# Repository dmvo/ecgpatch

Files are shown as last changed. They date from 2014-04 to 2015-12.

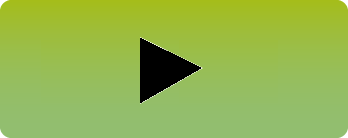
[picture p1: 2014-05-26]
ios/ECG/Pysty_Record.png

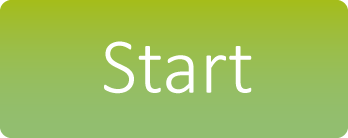
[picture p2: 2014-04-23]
ios/ECG/Pysty_Start.png

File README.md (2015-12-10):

ecgpatch
========

This repository contains source code related to the ECG patch
developed in Helsinki Metropolia University of Applied Sciences
in the context of the HealthSens project.

The code is published under a permissive license and it is
good to use as a basis for similar research projects or even
serve as a basis for commercial products. In the latter case
we ask to be contacted prioir to use.

Note that not all files in this repository are covered with
Helsinki Metropolia University of Applied Sciences copyright.
Some are from the chip vendor, for example, in which case
there is a note about this in the file itself. Refer to
the vendor license when copying and using such files.

The source layout is as follows:

board/ : contains Eagle files for the schematics and PCB

ios-new/ : sources of the iPhone/iPad app to read data
  from the sensor patch
  
ios/ : legacy iOS code, don't look there

sensor/ : nRF51 firmware for the ECG patch.

Build instructions
==================

Please follow the usual XCode build procedure to build the iOS app.
You need to have a valid developer license from Apple in order to
be able to work with the code.

Firmware should be built by issuing the `make' command in the `sensor'
subdirectory. It is expected that you have an ARM cross-compiler.
We have successfully used gcc version 4.7.3 (20130312), however
another, more recent, compiler should be suitable. Probably you
will need to edit the `Makefile.include' file to reflect your
settings such as project root directory and optimization options.

When build is complete, use the .hex file in the `src' subdirectory
to flash the nRF51 chip. The `flash' target in the Makefile will
help you do this provided you have set up the gdb and JLinkGDBServer
properly. Refer to the documentation of respective components for
details.

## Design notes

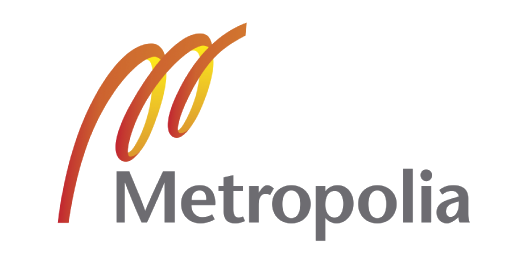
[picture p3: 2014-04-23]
ios/ECG/Metropolia_pysty.png

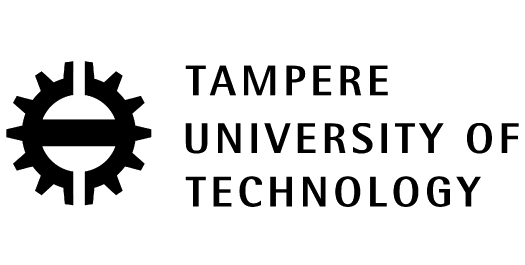
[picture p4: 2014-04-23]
ios/ECG/Tampere_Pysty.png

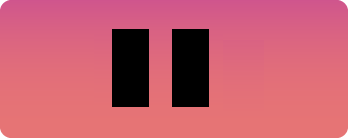
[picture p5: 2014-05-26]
ios/ECG/Pysty_Pause.png

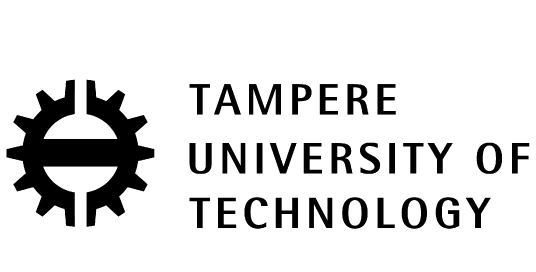
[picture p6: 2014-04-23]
ios/ECG/Tampere_Vaaka.png

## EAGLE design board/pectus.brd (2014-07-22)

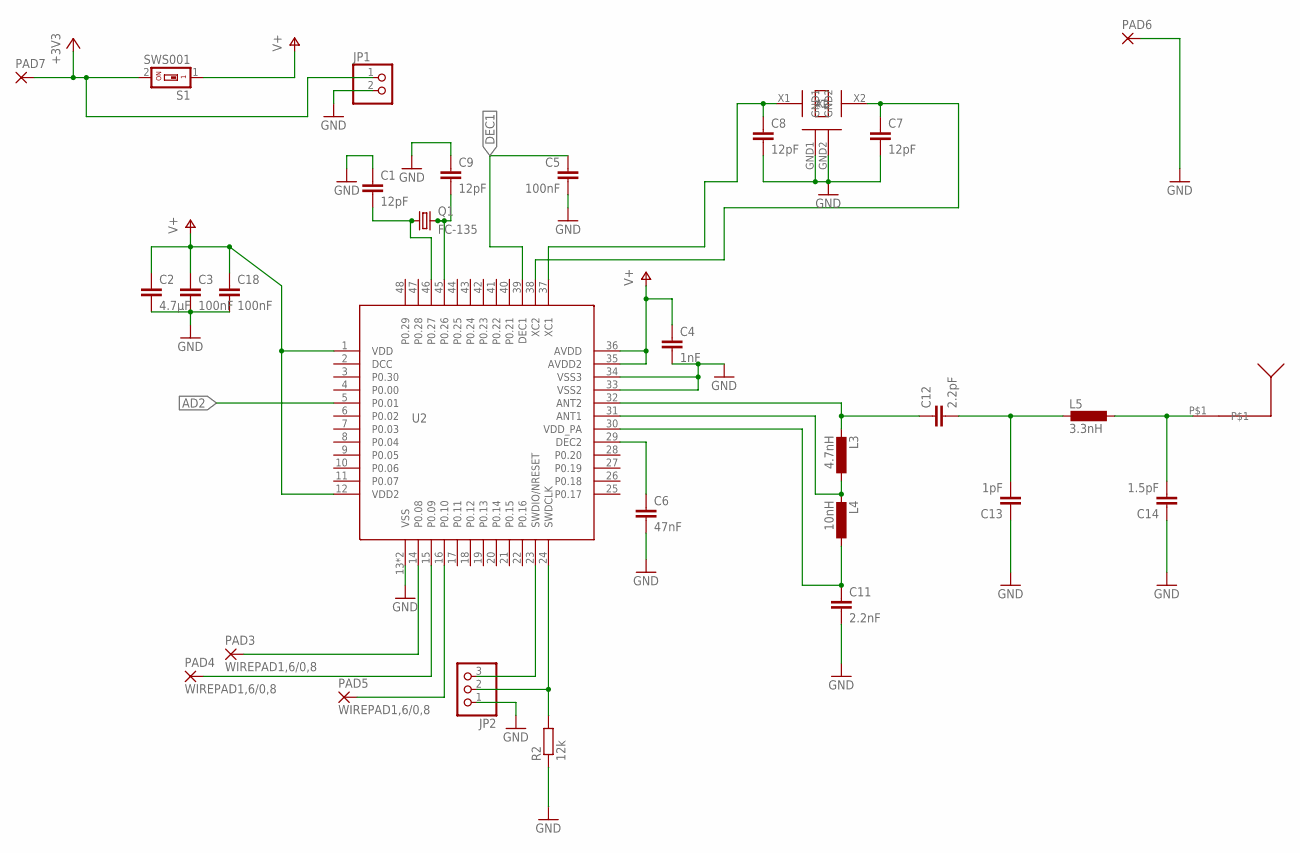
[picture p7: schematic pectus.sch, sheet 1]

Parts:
C1, C7, C8, C9: 12pF; C0603K
C2: 4.7µF; C0603K
C3, C5, C18: 100nF; C0603K
C4: 1nF; C0603K
C6: 47nF; C0603K
C11: 2.2nF; C0603
C12: 2.2pF; C0603
C13: 1pF; C0603
C14: 1.5pF; C0603
JP1: PINHD-1X2; 1X02
JP2: PINHD-1X3; 1X03
L3: 4.7nH; R0603
L4: 10nH; R0603
L5: 3.3nH; R0603
PAD3, PAD4, PAD5: WIREPAD1,6/0,8; 1,6/0,8
PAD6, PAD7: SMD5; SMD2,54-5,08
Q1: FC-135
R2: 12k; R0402
S1: SWS001; SMS-001
U2: NRF51822QFN; QFN48(6X6)
U$2: AVX16MHZOSCILLATOR
U$4: ANTENNA

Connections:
+3V3: JP1.1, PAD7.1, S1.2
AD2: U2.5 (P0.01); also elsewhere on the board
DEC1: C5.1, U2.39 (DEC1)
GND: C1.1, C2.2, C3.2, C4.2, C5.2, C6.2, C7.2, C8.2, C9.1, C11.2, C13.1, C14.1, C18.2, JP1.2, JP2.1, PAD6.1, R2.1, U2.13 (VSS), U2.33 (VSS2), U2.34 (VSS3), U2.P$49 (VSS), U$2.GND1, U$2.GND2; also elsewhere on the board
unnamed: C9.2, Q1.P$2 (2), U2.45 (P0.26)
unnamed: C1.2, Q1.P$1 (1), U2.46 (P0.27)
unnamed: PAD3.1, U2.14 (P0.08)
unnamed: PAD4.1, U2.15 (P0.09)
unnamed: PAD5.1, U2.16 (P0.10)
unnamed: C6.1, U2.29 (DEC2)
unnamed: JP2.3, U2.23 (SWDIO/NRESET)
unnamed: JP2.2, R2.2, U2.24 (SWDCLK)
unnamed: C8.1, U2.37 (XC1), U$2.X1
unnamed: C7.1, U2.38 (XC2), U$2.X2
unnamed: C11.1, L4.1, U2.30 (VDD_PA)
unnamed: L3.1, L4.2, U2.31 (ANT1)
unnamed: C12.1, L3.2, U2.32 (ANT2)
unnamed: C12.2, C13.2, L5.2
unnamed: C14.2, L5.1, U$4.P$1
V+: C2.1, C3.1, C4.1, C18.1, S1.1, U2.1 (VDD), U2.12 (VDD2), U2.35 (AVDD2), U2.36 (AVDD); also elsewhere on the board

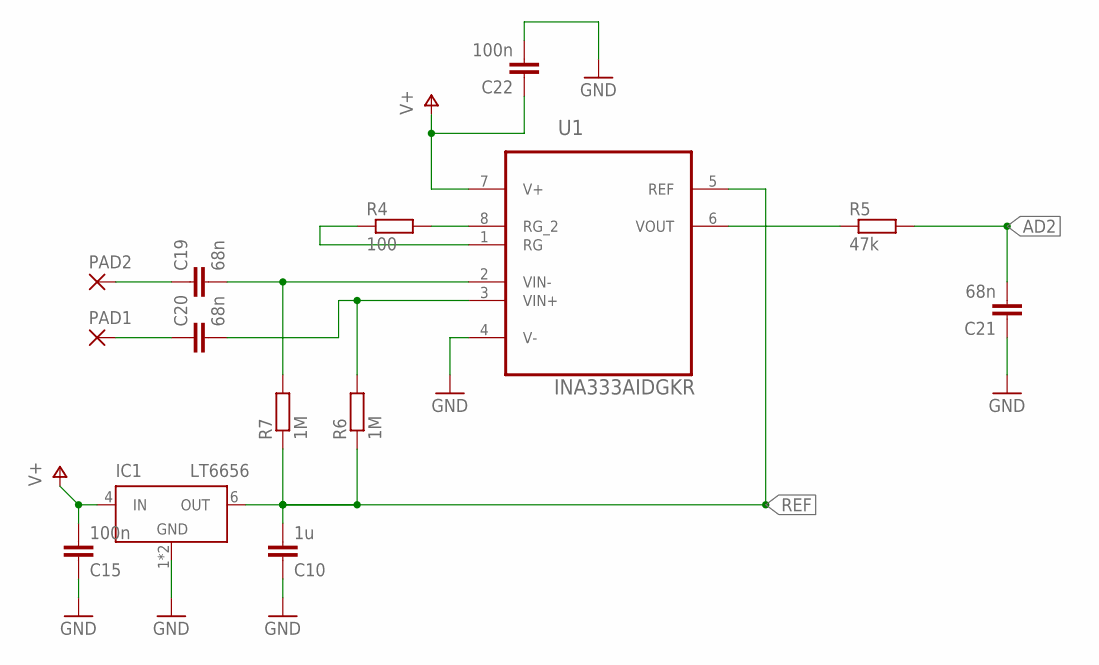
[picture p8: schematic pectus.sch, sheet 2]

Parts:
C10: 1u; C0603
C15, C22: 100n; C0603
C19, C20, C21: 68n; C0603
IC1: LT6656; TSOT23-6
PAD1, PAD2: 1,6/0,8
R4: 100; R0603
R5: 47k; R0603
R6, R7: 1M; R0603
U1: INA333AIDGKR; SOP65P490X110-8N

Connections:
AD2: C21.2, R5.2; also elsewhere on the board
GND: C10.1, C15.1, C21.1, C22.2, IC1.1 (GND), IC1.2 (GND), U1.4 (V-); also elsewhere on the board
unnamed: C19.1, PAD2.1
unnamed: R4.2, U1.8 (RG_2)
unnamed: C20.1, PAD1.1
unnamed: R4.1, U1.1 (RG)
unnamed: R5.1, U1.6 (VOUT)
unnamed: C19.2, R7.2, U1.2 (VIN-)
unnamed: C20.2, R6.2, U1.3 (VIN+)
REF: C10.2, IC1.6 (OUT), R6.1, R7.1, U1.5 (REF)
V+: C15.2, C22.1, IC1.4 (IN), U1.7 (V+); also elsewhere on the board

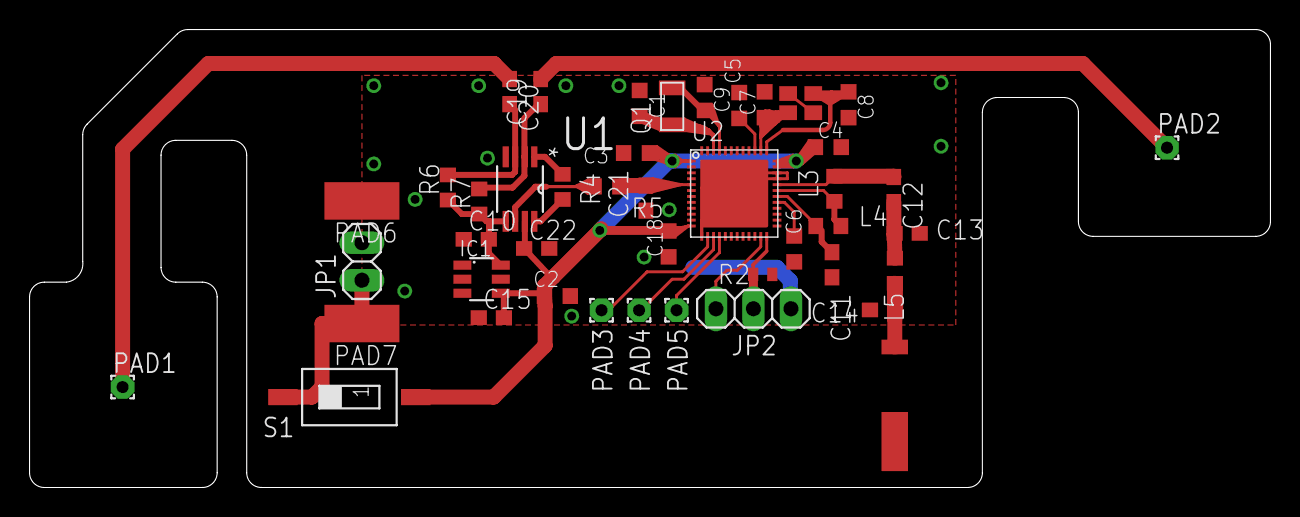
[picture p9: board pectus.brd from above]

Board: 2 copper layers, 84.0 x 31.0 mm, 44 parts (0 on the bottom side), 28 nets.

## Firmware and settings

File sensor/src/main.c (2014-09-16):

#include <stdint.h>
#include <string.h>
#include "nordic_common.h"
#include "nrf.h"
#include "app_error.h"
#include "nrf51_bitfields.h"
#include "ble.h"
#include "ble_hci.h"
#include "ble_srv_common.h"
#include "ble_advdata.h"
#include "ble_bas.h"
#include "ble_hrs.h"
#include "ble_conn_params.h"
#include "softdevice_handler.h"
#include "app_timer.h"
#include "ble_error_log.h"
#include "ble_debug_assert_handler.h"

#include "qrsdet.h"

#define DEVICE_NAME                          "Electria_HRM"                               /**< Name of device. Will be included in the advertising data. */
#define MANUFACTURER_NAME                    "NordicSemiconductor"                      /**< Manufacturer. Will be passed to Device Information Service. */
#define APP_ADV_INTERVAL                     40                                         /**< The advertising interval (in units of 0.625 ms. This value corresponds to 25 ms). */
#define APP_ADV_TIMEOUT_IN_SECONDS           180                                        /**< The advertising timeout in units of seconds. */

#define APP_TIMER_PRESCALER                  0                                          /**< Value of the RTC1 PRESCALER register. */
#define APP_TIMER_MAX_TIMERS                 3                                          /**< Maximum number of simultaneously created timers. */
#define APP_TIMER_OP_QUEUE_SIZE              4                                          /**< Size of timer operation queues. */

#define ADC_MEAS_INTERVAL             APP_TIMER_TICKS(5, APP_TIMER_PRESCALER)

#define MIN_CONN_INTERVAL                    MSEC_TO_UNITS(7.5, UNIT_1_25_MS)
#define MAX_CONN_INTERVAL                    MSEC_TO_UNITS(35, UNIT_1_25_MS)
#define SLAVE_LATENCY                        0                                          /**< Slave latency. */
#define CONN_SUP_TIMEOUT                     MSEC_TO_UNITS(4000, UNIT_10_MS)           /**< Connection supervisory timeout (4 seconds). */

#define FIRST_CONN_PARAMS_UPDATE_DELAY       APP_TIMER_TICKS(5000, APP_TIMER_PRESCALER) /**< Time from initiating event (connect or start of notification) to first time sd_ble_gap_conn_param_update is called (5 seconds). */
#define NEXT_CONN_PARAMS_UPDATE_DELAY        APP_TIMER_TICKS(5000, APP_TIMER_PRESCALER) /**< Time between each call to sd_ble_gap_conn_param_update after the first call (30 seconds). */
#define MAX_CONN_PARAMS_UPDATE_COUNT         3                                          /**< Number of attempts before giving up the connection parameter negotiation. */

#define SEC_PARAM_TIMEOUT                    30                                         /**< Timeout for Pairing Request or Security Request (in seconds). */
#define SEC_PARAM_BOND                       0                                          /**< Perform bonding. */
#define SEC_PARAM_MITM                       0                                          /**< Man In The Middle protection not required. */
#define SEC_PARAM_IO_CAPABILITIES            BLE_GAP_IO_CAPS_NONE                       /**< No I/O capabilities. */
#define SEC_PARAM_OOB                        0                                          /**< Out Of Band data not available. */
#define SEC_PARAM_MIN_KEY_SIZE               7                                          /**< Minimum encryption key size. */
#define SEC_PARAM_MAX_KEY_SIZE               16                                         /**< Maximum encryption key size. */

#define DEAD_BEEF                            0xDEADBEEF                                 /**< Value used as error code on stack dump, can be used to identify stack location on stack unwind. */

static uint16_t                              m_conn_handle = BLE_CONN_HANDLE_INVALID;   /**< Handle of the current connection. */
static ble_gap_sec_params_t                  m_sec_params;                              /**< Security requirements for this application. */
static ble_gap_adv_params_t                  m_adv_params;                              /**< Parameters to be passed to the stack when starting advertising. */
static ble_hrs_t                             m_hrs;                                     /**< Structure used to identify the heart rate service. */
static ble_bas_t                             m_bas;

static app_timer_id_t                        m_adc_timer_id;

static volatile uint16_t        s_cur_heart_rate;

#define ADC_ECG_SAMPLE ((ADC_CONFIG_RES_10bit << ADC_CONFIG_RES_Pos) | \
	(ADC_CONFIG_INPSEL_AnalogInputOneThirdPrescaling << ADC_CONFIG_INPSEL_Pos) | \
	(ADC_CONFIG_REFSEL_VBG << ADC_CONFIG_REFSEL_Pos) | \
	(ADC_CONFIG_PSEL_AnalogInput2 << ADC_CONFIG_PSEL_Pos) | \
	(ADC_CONFIG_EXTREFSEL_None << ADC_CONFIG_EXTREFSEL_Pos))

#define ADC_BAT_SAMPLE ((ADC_CONFIG_RES_8bit << ADC_CONFIG_RES_Pos) | \
	(ADC_CONFIG_INPSEL_SupplyOneThirdPrescaling << ADC_CONFIG_INPSEL_Pos) | \
	(ADC_CONFIG_REFSEL_VBG << ADC_CONFIG_REFSEL_Pos) | \
	(ADC_CONFIG_PSEL_Disabled << ADC_CONFIG_PSEL_Pos) | \
	(ADC_CONFIG_EXTREFSEL_None << ADC_CONFIG_EXTREFSEL_Pos))

void app_error_handler(uint32_t error_code, uint32_t line_num, const uint8_t * p_file_name)
{
	// This call can be used for debug purposes during application development.
	// @note CAUTION: Activating this code will write the stack to flash on an error.
	//                This function should NOT be used in a final product.
	//                It is intended STRICTLY for development/debugging purposes.
	//                The flash write will happen EVEN if the radio is active, thus interrupting
	//                any communication.
	//                Use with care. Uncomment the line below to use.
	// ble_debug_assert_handler(error_code, line_num, p_file_name);

	// On assert, the system can only recover with a reset.
	NVIC_SystemReset();
}

void assert_nrf_callback(uint16_t line_num, const uint8_t * p_file_name)
{
	app_error_handler(DEAD_BEEF, line_num, p_file_name);
}

static void adc_meas_timeout_handler(void *p_context)
{
	static uint32_t cnt;
	uint32_t hfclk_running = 0;

	if (!((cnt++) % 200))
		NRF_ADC->CONFIG = ADC_BAT_SAMPLE;

	NRF_ADC->TASKS_START = 1;
}

static void timers_init(void)
{
	uint32_t err_code;

	APP_TIMER_INIT(APP_TIMER_PRESCALER, APP_TIMER_MAX_TIMERS, APP_TIMER_OP_QUEUE_SIZE, false);

	err_code = app_timer_create(&m_adc_timer_id,
			APP_TIMER_MODE_REPEATED,
			adc_meas_timeout_handler);
	APP_ERROR_CHECK(err_code);
}

static void gap_params_init(void)
{
	uint32_t                err_code;
	ble_gap_conn_params_t   gap_conn_params;
	ble_gap_conn_sec_mode_t sec_mode;

	BLE_GAP_CONN_SEC_MODE_SET_OPEN(&sec_mode);

	err_code = sd_ble_gap_device_name_set(&sec_mode,
			(const uint8_t *)DEVICE_NAME,
			strlen(DEVICE_NAME));
	APP_ERROR_CHECK(err_code);

	err_code = sd_ble_gap_appearance_set(BLE_APPEARANCE_HEART_RATE_SENSOR_HEART_RATE_BELT);
	APP_ERROR_CHECK(err_code);

	memset(&gap_conn_params, 0, sizeof(gap_conn_params));

	gap_conn_params.min_conn_interval = MIN_CONN_INTERVAL;
	gap_conn_params.max_conn_interval = MAX_CONN_INTERVAL;
	gap_conn_params.slave_latency     = SLAVE_LATENCY;
	gap_conn_params.conn_sup_timeout  = CONN_SUP_TIMEOUT;

	err_code = sd_ble_gap_ppcp_set(&gap_conn_params);
	APP_ERROR_CHECK(err_code);
}

static void advertising_init(void)
{
	uint32_t      err_code;
	ble_advdata_t advdata;
	uint8_t       flags = BLE_GAP_ADV_FLAGS_LE_ONLY_GENERAL_DISC_MODE;

	ble_uuid_t adv_uuids[] =
	{
		{BLE_UUID_HEART_RATE_SERVICE, BLE_UUID_TYPE_BLE},
		{BLE_UUID_BATTERY_SERVICE, BLE_UUID_TYPE_BLE},
	};

	// Build and set advertising data.
	memset(&advdata, 0, sizeof(advdata));

	advdata.name_type               = BLE_ADVDATA_FULL_NAME;
	advdata.include_appearance      = true;
	advdata.flags.size              = sizeof(flags);
	advdata.flags.p_data            = &flags;
	advdata.uuids_complete.uuid_cnt = sizeof(adv_uuids) / sizeof(adv_uuids[0]);
	advdata.uuids_complete.p_uuids  = adv_uuids;

	err_code = ble_advdata_set(&advdata, NULL);
	APP_ERROR_CHECK(err_code);

	// Initialize advertising parameters (used when starting advertising).
	memset(&m_adv_params, 0, sizeof(m_adv_params));

	m_adv_params.type        = BLE_GAP_ADV_TYPE_ADV_IND;
	m_adv_params.p_peer_addr = NULL;                           // Undirected advertisement.
	m_adv_params.fp          = BLE_GAP_ADV_FP_ANY;
	m_adv_params.interval    = APP_ADV_INTERVAL;
	m_adv_params.timeout     = APP_ADV_TIMEOUT_IN_SECONDS;
}

static void services_init(void)
{
	uint32_t       err_code;
	ble_hrs_init_t hrs_init;
	ble_bas_init_t bas_init;
	uint8_t        body_sensor_location;

	/* Initialize Heart Rate Service. */
	body_sensor_location = BLE_HRS_BODY_SENSOR_LOCATION_CHEST;

	memset(&hrs_init, 0, sizeof(hrs_init));

	hrs_init.evt_handler                 = NULL;
	hrs_init.is_sensor_contact_supported = false;
	hrs_init.p_body_sensor_location      = &body_sensor_location;

	/* Here the sec level for the Heart Rate Service can be changed/increased. */
	BLE_GAP_CONN_SEC_MODE_SET_OPEN(&hrs_init.hrs_hrm_attr_md.cccd_write_perm);
	BLE_GAP_CONN_SEC_MODE_SET_NO_ACCESS(&hrs_init.hrs_hrm_attr_md.read_perm);
	BLE_GAP_CONN_SEC_MODE_SET_NO_ACCESS(&hrs_init.hrs_hrm_attr_md.write_perm);

	BLE_GAP_CONN_SEC_MODE_SET_OPEN(&hrs_init.hrs_bsl_attr_md.read_perm);
	BLE_GAP_CONN_SEC_MODE_SET_NO_ACCESS(&hrs_init.hrs_bsl_attr_md.write_perm);

	err_code = ble_hrs_init(&m_hrs, &hrs_init);
	APP_ERROR_CHECK(err_code);

	/* Initialize Battery Service */
	memset(&bas_init, 0, sizeof(bas_init));

	/* Here the sec level for the Battery Service can be changed/increased. */
	BLE_GAP_CONN_SEC_MODE_SET_OPEN(&bas_init.battery_level_char_attr_md.cccd_write_perm);
	BLE_GAP_CONN_SEC_MODE_SET_OPEN(&bas_init.battery_level_char_attr_md.read_perm);
	BLE_GAP_CONN_SEC_MODE_SET_NO_ACCESS(&bas_init.battery_level_char_attr_md.write_perm);
	BLE_GAP_CONN_SEC_MODE_SET_OPEN(&bas_init.battery_level_report_read_perm);

	bas_init.evt_handler          = NULL;
	bas_init.support_notification = true;
	bas_init.p_report_ref         = NULL;
	bas_init.initial_batt_level   = 100;

	err_code = ble_bas_init(&m_bas, &bas_init);
	APP_ERROR_CHECK(err_code);
}

static void sec_params_init(void)
{
	m_sec_params.timeout      = SEC_PARAM_TIMEOUT;
	m_sec_params.bond         = SEC_PARAM_BOND;
	m_sec_params.mitm         = SEC_PARAM_MITM;
	m_sec_params.io_caps      = SEC_PARAM_IO_CAPABILITIES;
	m_sec_params.oob          = SEC_PARAM_OOB;
	m_sec_params.min_key_size = SEC_PARAM_MIN_KEY_SIZE;
	m_sec_params.max_key_size = SEC_PARAM_MAX_KEY_SIZE;
}

static void adc_init(void)
{
	NRF_ADC->INTENSET = ADC_INTENSET_END_Msk;   
	sd_nvic_SetPriority(ADC_IRQn, NRF_APP_PRIORITY_LOW);  
	sd_nvic_EnableIRQ(ADC_IRQn);
	NRF_ADC->CONFIG = ADC_ECG_SAMPLE;
	NRF_ADC->ENABLE = ADC_ENABLE_ENABLE_Enabled;
}

static void application_timers_start(void)
{
	uint32_t err_code;

	err_code = app_timer_start(m_adc_timer_id, ADC_MEAS_INTERVAL, NULL);
	APP_ERROR_CHECK(err_code);
}

static void advertising_start(void)
{
	uint32_t err_code;

	err_code = sd_ble_gap_adv_start(&m_adv_params);
	APP_ERROR_CHECK(err_code);
}

static void on_conn_params_evt(ble_conn_params_evt_t *p_evt)
{
	uint32_t err_code;

	if(p_evt->evt_type == BLE_CONN_PARAMS_EVT_FAILED)
	{
		err_code = sd_ble_gap_disconnect(m_conn_handle, BLE_HCI_CONN_INTERVAL_UNACCEPTABLE);
		APP_ERROR_CHECK(err_code);
	}
}

static void conn_params_error_handler(uint32_t nrf_error)
{
    APP_ERROR_HANDLER(nrf_error);
}

static void conn_params_init(void)
{
	uint32_t               err_code;
	ble_conn_params_init_t cp_init;

	memset(&cp_init, 0, sizeof(cp_init));

	cp_init.p_conn_params                  = NULL;
	cp_init.first_conn_params_update_delay = FIRST_CONN_PARAMS_UPDATE_DELAY;
	cp_init.next_conn_params_update_delay  = NEXT_CONN_PARAMS_UPDATE_DELAY;
	cp_init.max_conn_params_update_count   = MAX_CONN_PARAMS_UPDATE_COUNT;
	cp_init.start_on_notify_cccd_handle    = m_hrs.hrm_handles.cccd_handle;
	cp_init.disconnect_on_fail             = false;
	cp_init.evt_handler                    = on_conn_params_evt;
	cp_init.error_handler                  = conn_params_error_handler;

	err_code = ble_conn_params_init(&cp_init);
	APP_ERROR_CHECK(err_code);
}

static void on_ble_evt(ble_evt_t * p_ble_evt)
{
    uint32_t err_code;

    switch (p_ble_evt->header.evt_id)
    {
        case BLE_GAP_EVT_CONNECTED:

            m_conn_handle = p_ble_evt->evt.gap_evt.conn_handle;
            break;

        case BLE_GAP_EVT_DISCONNECTED:

            m_conn_handle = BLE_CONN_HANDLE_INVALID;

            advertising_start();
            break;

        case BLE_GAP_EVT_SEC_PARAMS_REQUEST:
            err_code = sd_ble_gap_sec_params_reply(m_conn_handle,
                                                   BLE_GAP_SEC_STATUS_SUCCESS,
                                                   &m_sec_params);
            APP_ERROR_CHECK(err_code);
            break;

        case BLE_GAP_EVT_TIMEOUT:
            if (p_ble_evt->evt.gap_evt.params.timeout.src == BLE_GAP_TIMEOUT_SRC_ADVERTISEMENT)
            {
                err_code = sd_power_system_off();
                APP_ERROR_CHECK(err_code);
            }
            break;

        default:
            break;
    }
}

void ADC_IRQHandler(void)
{
	volatile uint32_t result;
	static uint32_t ticks, prev_ticks;
	uint32_t delay;
	uint16_t rr_interval;
	uint32_t err_code;
	static bool tosend = true;

	NRF_ADC->EVENTS_END = 0;
	result = NRF_ADC->RESULT;
	NRF_ADC->TASKS_STOP = 1;

	if (NRF_ADC->CONFIG == ADC_BAT_SAMPLE) {
		// Process the bat status and send it out
		// [TODO]
		// bring the config back to "normal" ECG
		// not to touch it before the next battery
		// measurement
		//
		NRF_ADC->CONFIG = ADC_ECG_SAMPLE;
		// restart the ADC to take the sample for
		// Pan-Tompkins
		NRF_ADC->TASKS_START = 1;
	} else {
		delay = QRSDet(result, 0);

		if (delay) {
			prev_ticks = ticks;
			app_timer_cnt_get(&ticks);
			rr_interval = (60 * APP_TIMER_CLOCK_FREQ) / ((APP_TIMER_PRESCALER
						+ 1) * (ticks - prev_ticks));
			ble_hrs_rr_interval_add(&m_hrs, rr_interval);
		}

		if (tosend) {
			s_cur_heart_rate = result;

			err_code = ble_hrs_heart_rate_measurement_send(&m_hrs,
					s_cur_heart_rate);
			if ((err_code != NRF_SUCCESS) &&
					(err_code != NRF_ERROR_INVALID_STATE)
					&& (err_code != BLE_ERROR_NO_TX_BUFFERS)
					&& (err_code != BLE_ERROR_GATTS_SYS_ATTR_MISSING)) {
			}
		}

		tosend = !tosend;
	}

}

static void ble_evt_dispatch(ble_evt_t * p_ble_evt)
{
	ble_bas_on_ble_evt(&m_bas, p_ble_evt);
	ble_hrs_on_ble_evt(&m_hrs, p_ble_evt);
	ble_conn_params_on_ble_evt(p_ble_evt);
	on_ble_evt(p_ble_evt);
}

static void sys_evt_dispatch(uint32_t sys_evt)
{
}

static void ble_stack_init(void)
{
	uint32_t err_code;

	SOFTDEVICE_HANDLER_INIT(NRF_CLOCK_LFCLKSRC_XTAL_20_PPM, false);

	err_code = softdevice_ble_evt_handler_set(ble_evt_dispatch);
	APP_ERROR_CHECK(err_code);

	err_code = softdevice_sys_evt_handler_set(sys_evt_dispatch);
	APP_ERROR_CHECK(err_code);
}

static void power_manage(void)
{
	uint32_t err_code = sd_app_evt_wait();
	APP_ERROR_CHECK(err_code);
}

int main(void)
{
	QRSDet(0, 1);	

	ble_stack_init();
	timers_init();
	adc_init();

	gap_params_init();
	advertising_init();
	services_init();
	conn_params_init();
	sec_params_init();

	application_timers_start();
	advertising_start();

	for (;;)
	{
		power_manage();
	}
}

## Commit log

2014-04-16 FW: switch to using 32 kHz crystal in LFCLK
    I need to force myself to abandon the old boards, which didn't have
    crystals on them. This patch, which switches from the RC oscillator
    to the 32 kHz crystal, can help me do that.
    [main.c]
2014-04-17 SENSOR: rearrange LDFLAGS to get working binary
    I had a strange glitch when GNU ld failed to produce a working
    binary with a "wrong" order of options in LDFLAGS. After trial
    and error, "good" order was found and provided in this patch.
    While at it, we add another target to the Makefile: ihex firmware.
2014-04-17 BLE: add battery service sources
    This patch prepares us for adding the battery level indicator to our
    sensor, and we add the source code and header file for the BAS.
    We also include the BAS source code into the build system for our
    firmware.
2014-04-17 SENSOR: add Battery Service, part I
    This patch adds the following to the sensor application:
    o Battery service UUID to be advertised
    o Battery service initialization
    o Battery service event handling
    TODO: add timer-based battery level measurement and send the values.
2014-04-17 SENSOR: rename timer
    We are going to multiplex ADC measurements for both the battery level
    and the ECG signal. The timer, which will trigger both measurements,
    will be the same, and for this reason this timer should be referred
    to as an "ADC timer", not the "Heart rate timer". This patch renames
    the timer to match its functionality.
2014-04-23 SENSOR: use our ar instead of Xcode's
    There were cryptic errors when using Xcode's ar, so we explicitly
    enable ar from our cross-compilation package.
2014-04-23 SENSOR: replace the sensor location to CHEST
    ...because it is where we actually keep it.
    [main.c]
2014-04-23 IOS: cleanup: remove device info parser
    In the current version of our firmware we aren't sending device info
    anyway, so let's remoe unused code for now.
2014-04-24 IOS: move the BPM label
    We need to make room for our future elements in the UI:
    o the battery status label
    o ECG recording widgets
    So we move the BPM label a bit left and up.
    While at it, we clean up our code a bit.
2014-04-24 IOS: add label for battery status
    This patch only changes the storyboard. Code will be added later.
2014-04-24 IOS: remove parsing device name
    I am anyway not having device information sensor-side, so remove
    device name parsing code for now. Anyway, Xcode was complaining
    about something obsolete in that parser.
2014-04-25 IOS: add battery level display
    This patch adds the iOS-side code to enable the Battery service
    on the peripheral side and to display the battery level on the
    text label we introduced earlier.
    TODO: clean up logging, which is currently quite excessive, at
    least to my taste.
2014-06-06 Basic functionality for searching devices, connecting and disconnecting complete.
2014-06-09 IOS-NEW: move the CorePlot framework to out iOS directory
2014-06-09 IOS-NEW: remove unused directories
    While merging the CorePlot code we inherited a lot of
    directories that we'll never need. This patch removes
    them all.
    [piezoresonance.csv]
2014-06-17 [IOS-NEW] Implement basic plotting
    This patch adds basic real-time plotting functionality. We add the CorePlot
    framework and all things needed to catch the ECG samples and draw the
    signal as it arrives.
    TODO:
    1. Try to accelerate animation
    2. Do automatic range calculations
    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
2014-07-18 [IOS] Change recording time to 2h
    Along the way many other changes that are hard to
    document, as it is always the case in Xcode.
2014-07-22 HARDWARE: add Eagle design files
    [pectus.brd, pectus.sch]
2014-09-05 SENSOR: Factor out ADC config for the "normal" ECG sampling
    We are trying to multiplex the ADC timer for serving two purposes:
    sample the battery level as well as take "normal" ECG samples from
    the ADC pin connected to the output of the preamplifier. This patch
    is part of preparation for multiplexor implementation. It factors
    out the ADC config suitable for the former purpose.
    While at it, we clean up the age-old commented out code that kept
    LFCLK-less configuration of the soft device. We now have the 32 kHz
    oscillator available on all the devices that we use, so the
    RC-based LF clock isn't needed any longer.
    [main.c]
2014-09-08 SENSOR: Add battery level sampling code
    This patch adds battery sampling at every 200th timer firing,
    which means we measure the battery voltage once a second. No
    sending the battery status to the air yet, nor is any of the
    necessary iOS side code implemented.
    While at it, we clean up the high_precision option that never
    came into use.
2014-09-16 SENSOR: change spaces to tabs
    Having spaces instead of tabs has annoyed me for quite a long time
    so now finally do it right.
